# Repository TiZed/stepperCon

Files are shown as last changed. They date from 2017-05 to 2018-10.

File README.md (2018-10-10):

<b>stepperCon</b> is a PIC18F46K22 based stepper motor controller.

It was created as an exercise in controlling stepper motors for a CNC project. The board and firmware were designed to drive a L298P driver but can probably be adapted to other drivers.

'master' branch - Has hybrid PWM-analog current control. <br />
'a2d_pid' branch - Has the ADC PI current control, not stable yet.

Some of the feature of this project:
- Micro-stepping, selectable up to 16 micro-steps.
- Current limiting.
- I2C interface for configuration.
- Two indicator LEDs.

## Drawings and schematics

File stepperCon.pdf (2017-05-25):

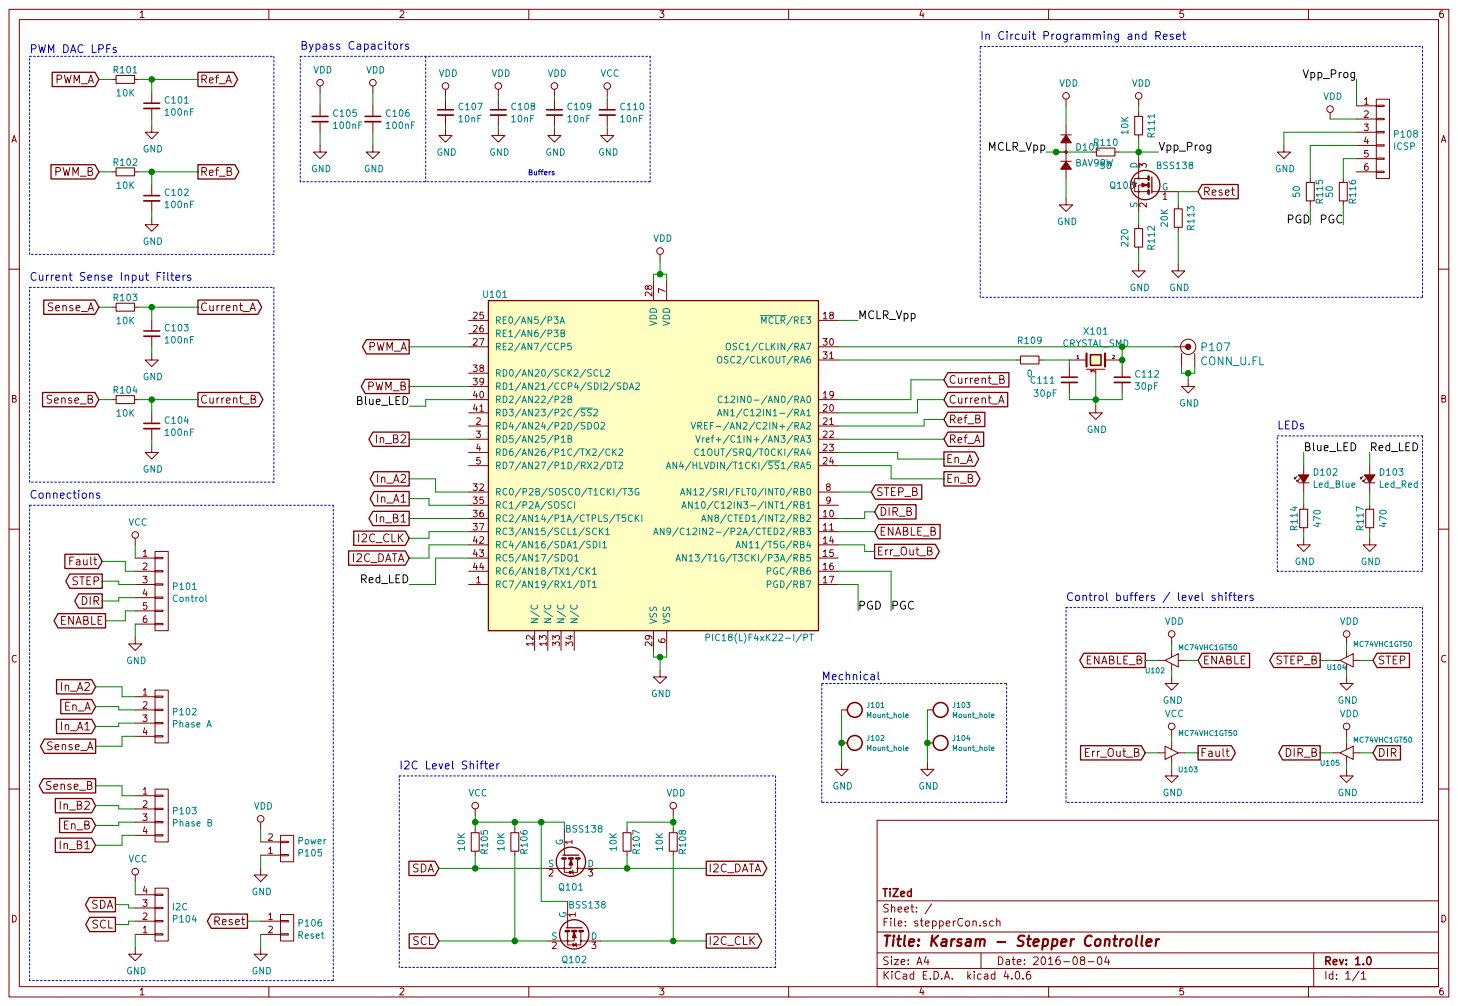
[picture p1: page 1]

In Circuit Programming and Reset

Current Sense Input Filters

7 AN12/SRI/FLT0/INT0/RB0 8 AN10/C12IN3-/INT1/RB1 9 AN8/CTED1/INT2/RB2 10 AN1/C12IN1-/RA1 20 OSC1/CLKIN/RA7 30 RD2/AN22/P2B 40 AN9/C12IN2-/P2A/CTED2/RB3 11 VREF-/AN2/C2IN+/RA2 21 OSC2/CLKOUT/RA6 31 RD3/AN23/P2C/SS2 41 N/C 12 Vref+/C1IN+/AN3/RA3 22 RC0/P2B/SOSCO/T1CKI/T3G 32 RC4/AN16/SDA1/SDI1 42 N/C 13 C1OUT/SRQ/T0CKI/RA4 23 N/C 33 RC5/AN17/SDO1 43 AN11/T5G/RB4 14 AN4/HLVDIN/T1CKI/SS1/RA5 24 N/C 34 RC6/AN18/TX1/CK1 44 AN13/T1G/T3CKI/P3A/RB5 15 RE0/AN5/P3A 25 RC1/P2A/SOSCI 35 PGC/RB6 16 RE1/AN6/P3B 26 RC2/AN14/P1A/CTPLS/T5CKI 36 PGD/RB7 17 RE2/AN7/CCP5 27 RC3/AN15/SCL1/SCK1 37 MCLR/RE3 18 VDD 28 RD0/AN20/SCK2/SCL2 38 C12IN0-/AN0/RA0 19 VSS 29 RD1/AN21/CCP4/SDI2/SDA2 39U101 PIC18(L)F4xK22-I/PT

Control buffers / level shifters

Id: 1/1 Title: Karsam - Stepper Controller

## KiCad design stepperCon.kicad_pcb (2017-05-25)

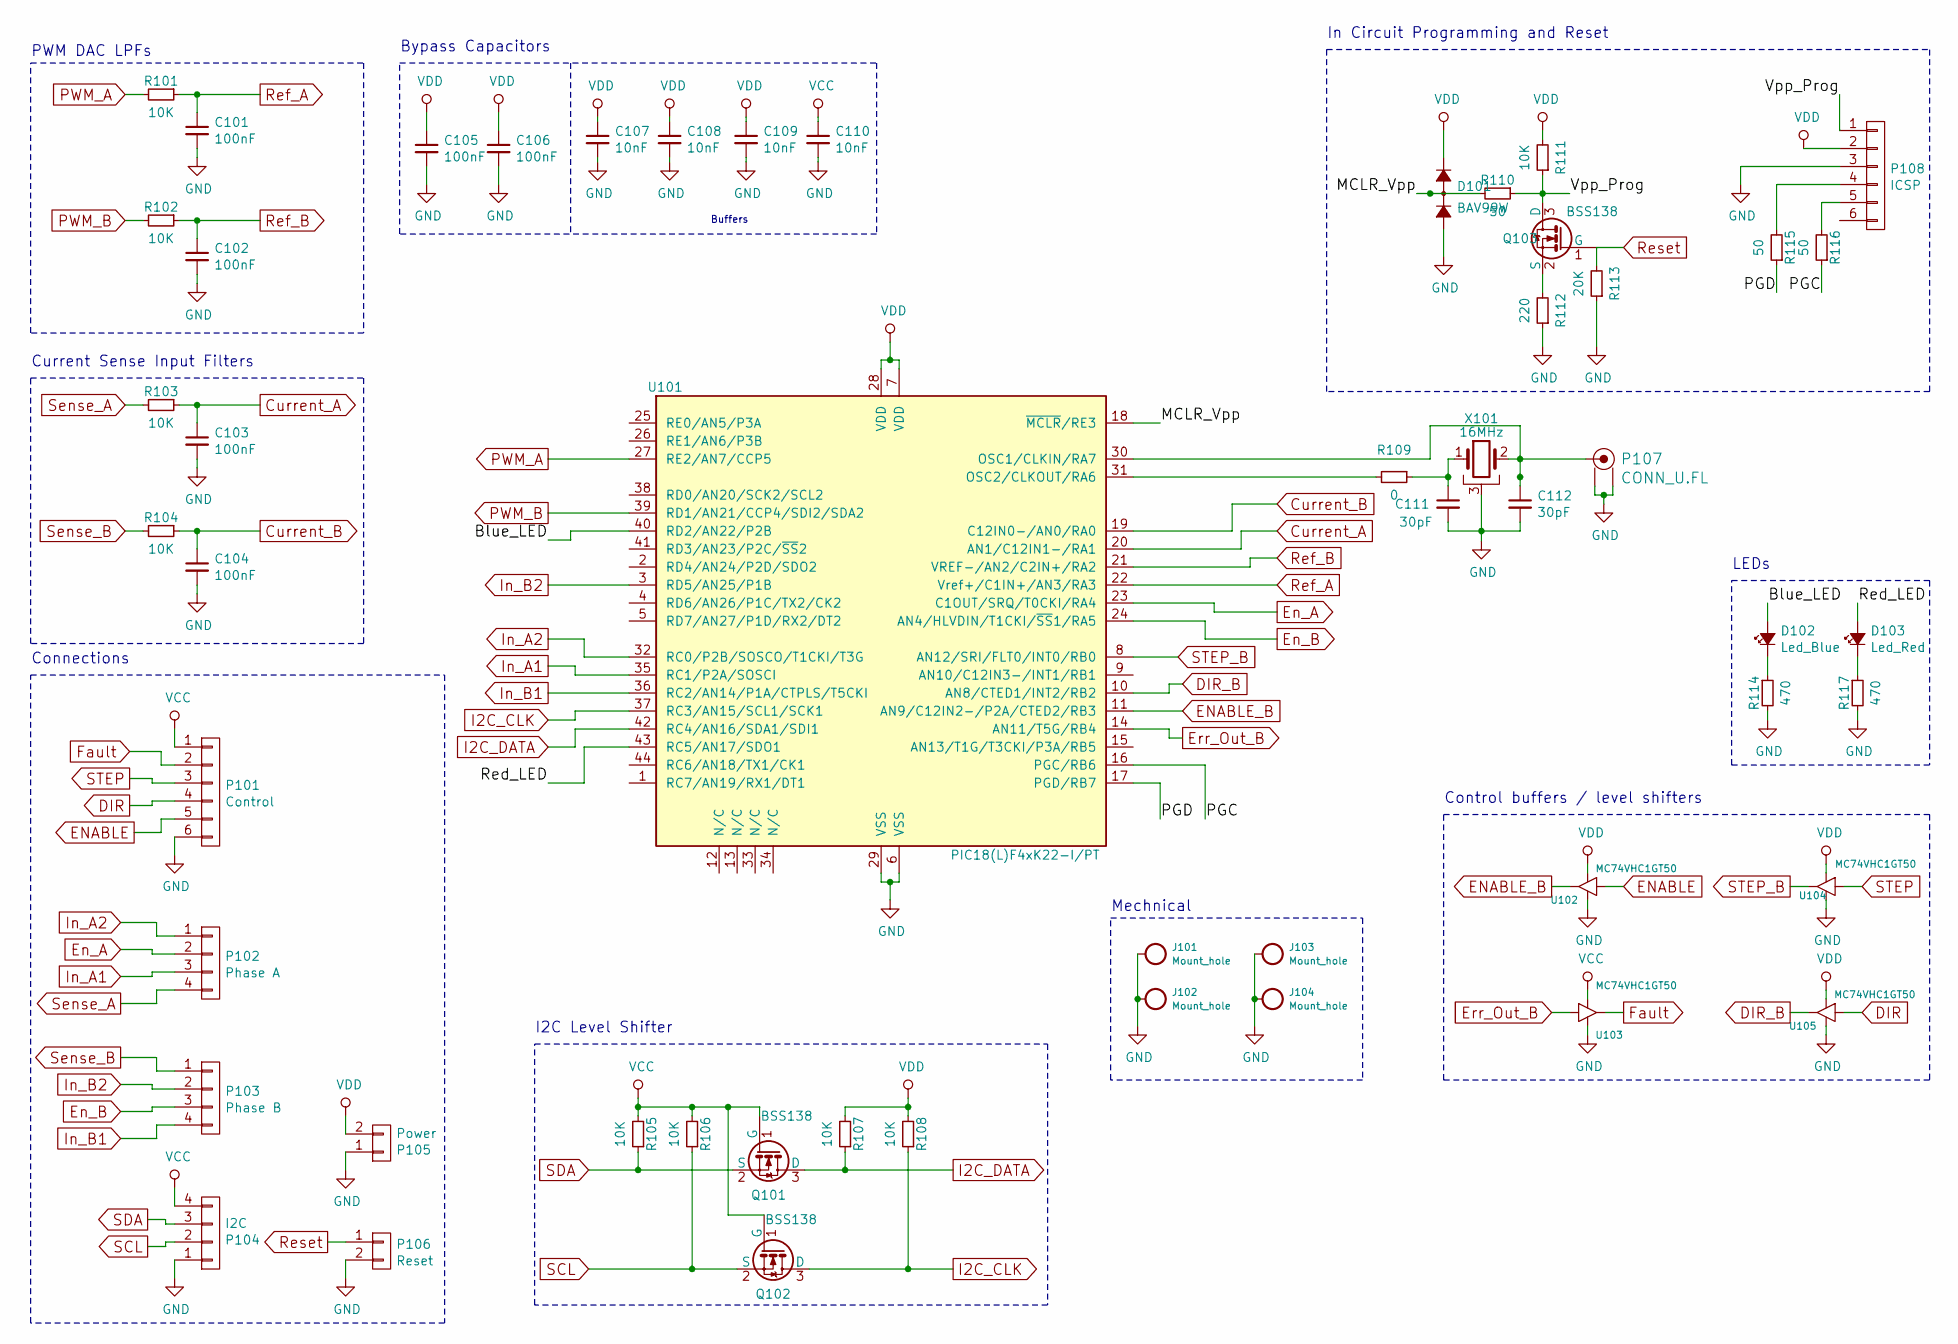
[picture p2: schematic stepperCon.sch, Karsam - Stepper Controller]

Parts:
C101, C102, C103, C104, C105, C106: 100nF; C_0603
C107, C108, C109, C110: 10nF; C_0603
C111, C112: 30pF; C_0603
D101: BAV99W; SOT-323
D102: Led_Blue; LED_0805
D103: Led_Red; LED_0805
J101, J102, J103, J104: Mount_hole; MountingHole_3.2mm_M3_Pad
P101: Control; Socket_Strip_Straight_1x06
P102: Phase A; Socket_Strip_Straight_1x04
P103: Phase B; Socket_Strip_Straight_1x04
P104: I2C; Socket_Strip_Straight_1x04
P105: Power; Socket_Strip_Straight_1x02
P106: Reset; Socket_Strip_Straight_1x02
P107: CONN_U.FL; UFL
P108: ICSP
Q101, Q102, Q103: BSS138; SOT-323
R101, R102, R103, R104, R105, R106, R107, R108, R111: 10K; R_0603
R109: 0; R_0603
R110, R115, R116: 50; R_0603
R112: 220; R_0603
R113: 20K; R_0603
R114, R117: 470; R_0603
U101: PIC18(L)F4xK22-I/PT; TQFP-44_10x10mm_Pitch0.8mm
U102, U103, U104, U105: MC74VHC1GT50; SOT-353
X101: 16MHz

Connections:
/Blue_LED: D102.2 (A), U101.40 (RD2/AN22/P2B)
/MCLR_Vpp: D101.3 (AK), R110.2, U101.18 (~MCLR~/RE3)
/PGC: R116.1, U101.16 (PGC/RB6)
/PGD: R115.1, U101.17 (PGD/RB7)
/Red_LED: D103.2 (A), U101.43 (RC5/AN17/SDO1)
/Vpp_Prog: P108.1, Q103.3 (D), R110.1, R111.1
Current_A: C103.1, R103.1, U101.20 (AN1/C12IN1-/RA1)
Current_B: C104.1, R104.1, U101.19 (C12IN0-/AN0/RA0)
DIR: P101.4, U105.2 (IN_A)
DIR_B: U101.10 (AN8/CTED1/INT2/RB2), U105.4 (OUT_Y)
ENABLE: P101.5, U102.2 (IN_A)
ENABLE_B: U101.11 (AN9/C12IN2-/P2A/CTED2/RB3), U102.4 (OUT_Y)
En_A: P102.2, U101.23 (C1OUT/SRQ/T0CKI/RA4)
En_B: P103.3, U101.24 (AN4/HLVDIN/T1CKI/~SS~1/RA5)
Err_Out_B: U101.14 (AN11/T5G/RB4), U103.2 (IN_A)
Fault: P101.2, U103.4 (OUT_Y)
GND: C101.2, C102.2, C103.2, C104.2, C105.2, C106.2, C107.2, C108.2, C109.2, C110.2, C111.2, C112.2, D101.1 (K), J101.1, J102.1, J103.1, J104.1, P101.6, P104.1, P105.1, P106.2, P107.2, P107.3, P108.3, R112.1, R113.1, R114.2, R117.2, U101.6 (VSS), U101.29 (VSS), U102.3 (GND), U103.3 (GND), U104.3 (GND), U105.3 (GND), X101.3
I2C_CLK: Q102.3 (D), R108.1, U101.37 (RC3/AN15/SCL1/SCK1)
I2C_DATA: Q101.3 (D), R107.1, U101.42 (RC4/AN16/SDA1/SDI1)
In_A1: P102.3, U101.35 (RC1/P2A/SOSCI)
In_A2: P102.1, U101.32 (RC0/P2B/SOSCO/T1CKI/T3G)
In_B1: P103.4, U101.36 (RC2/AN14/P1A/CTPLS/T5CKI)
In_B2: P103.2, U101.3 (RD5/AN25/P1B)
unnamed: C111.1, R109.1, X101.1
unnamed: C112.1, P107.1, U101.30 (OSC1/CLKIN/RA7), X101.2
unnamed: D102.1 (K), R114.1
unnamed: D103.1 (K), R117.1
unnamed: P108.4, R115.2
unnamed: P108.5, R116.2
unnamed: Q103.2 (S), R112.2
unnamed: R109.2, U101.31 (OSC2/CLKOUT/RA6)
PWM_A: R101.2, U101.27 (RE2/AN7/CCP5)
PWM_B: R102.2, U101.39 (RD1/AN21/CCP4/SDI2/SDA2)
Ref_A: C101.1, R101.1, U101.22 (Vref+/C1IN+/AN3/RA3)
Ref_B: C102.1, R102.1, U101.21 (VREF-/AN2/C2IN+/RA2)
Reset: P106.1, Q103.1 (G), R113.2
SCL: P104.2, Q102.2 (S), R106.1
SDA: P104.3, Q101.2 (S), R105.1
STEP: P101.3, U104.2 (IN_A)
STEP_B: U101.8 (AN12/SRI/FLT0/INT0/RB0), U104.4 (OUT_Y)
Sense_A: P102.4, R103.2
Sense_B: P103.1, R104.2
VCC: C110.1, P101.1, P104.4, Q101.1 (G), Q102.1 (G), R105.2, R106.2, U103.5 (VCC)
VDD: C105.1, C106.1, C107.1, C108.1, C109.1, D101.2 (A), P105.2, P108.2, R107.2, R108.2, R111.2, U101.7 (VDD), U101.28 (VDD), U102.5 (VCC), U104.5 (VCC), U105.5 (VCC)

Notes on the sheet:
I2C Level Shifter
PWM DAC LPFs
Current Sense Input Filters
Mechnical
Connections
Control buffers / level shifters
Bypass Capacitors
Buffers
LEDs
In Circuit Programming and Reset

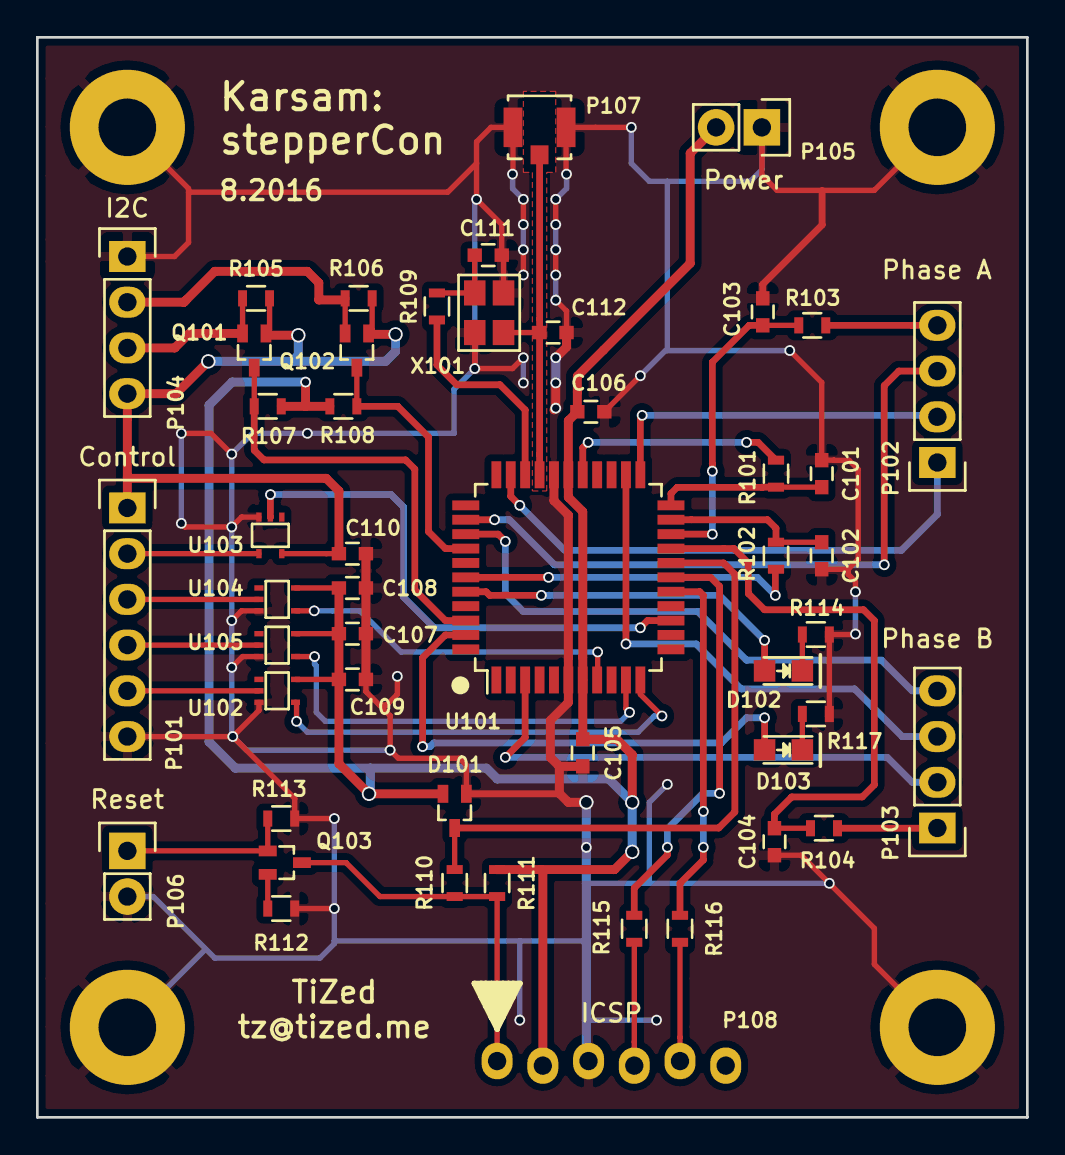
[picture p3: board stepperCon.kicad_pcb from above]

Board: 2 copper layers, 55.0 x 60.0 mm, 53 parts (0 on the bottom side), 44 nets.

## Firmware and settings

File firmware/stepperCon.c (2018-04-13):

/* 
 * File:   stepperCon.c
 * Author: TiZed
 *
 * Created on 12 August 2016
 * 
 *  Copyright (C) 2016 TiZed
 *
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
 * ----------------------------------------------------------------------------
 * 
 * 
 * * Phase A:
 * -------
 * RA1 - C12IN1- - Current sense in
 * RC1 - P2A - A1 Output
 * RC0 - P2B - A2 Output
 * RE2 - CCP5 - Analog out, connects to phase enable or AN3
 * RA3 - C1IN+ - Get reference voltage from PWM
 * RA4 - C1OUT - Phase enable signal from comparator
 * 
 * Phase B:
 * -------
 * RA0 - C12IN0- - Current sense in
 * RC2 - P1A - B1 Output
 * RD5 - P1B - B2 Output
 * RD1 - CCP4 - Analog out, connects to phase enable or AN3
 * RA2 - C2IN+ - Get reference voltage from PWM
 * RA5 - C2OUT - Phase enable signal from comparator
 * 
 * Controller I/F:
 * --------------
 * RB2 - INT2 - Direction Input
 * RB0 - INT0 - Step Input
 * RB3 - Enable Input
 * RB4 - Fault output
 * 
 * RC4 - SDA1 - I2C Data
 * RC3 - SCL1 - Clock
 * 
 * RD2 - Blue LED
 * RC5 - Red LED
 * 
 */

#include <pic18fregs.h>
#include <stdint.h>
#include <float.h>
#include <math.h>

#include "registers.h"

#pragma config  FOSC    = HSHP      // HS ocsillator, high power
#pragma config  PLLCFG  = ON        // x4 PLL on
#pragma config  WDTEN   = SWON      // WDT software controlled
#pragma config  XINST   = OFF       // For SDCC
#pragma config  CCP3MX  = PORTE0    // CCP3 on port E0   
#pragma config  P2BMX   = PORTC0    // P2B on port C0
#pragma config  MCLRE   = EXTMCLR   // Enable MCLR pin (E3 disabled)
// #pragma config  LVP     = ON        // Low voltage programming enabled

#define STEPS 16
#define FULL_CYCLE (4 * STEPS)
#define HALF_CYCLE (2 * STEPS)
#define THREE_QUARTERS (3 * STEPS)

// Some default values
#define CUR_GAIN 90         // Current sensor gain

#define I2C_ADDRESS 0x40    // X- 0x40, Y- 0x42, Z- 0x44 
#define I2C_REGISTERS 9


#define MAX_AMP 3704        // [mA] Maximum driver amperage
#define SET_AMP 1500        // [mA] Default driver limit
#define T_OFF   20          // [usec.] fixed phase time off
#define T_BLANK_HIGH 1      // [usec.] blank time for forward current
#define T_BLANK_LOW  10     // [usec.] blank time for revers current

// Stepping modes
#define STEP_16  1
#define STEP_8   2
#define STEP_4   4
#define STEP_2   8
#define STEP_1  16

// Decay modes
#define SLOW_DECAY 0
#define FAST_DECAY 1

// System states
#define IDLE      0
#define START     1
#define RUNNING   2
#define HALT      3
#define STEP      4
#define NEXT_STEP 6

// Phase states
#define PH_BLANK    0
#define PH_OFF      1
#define T_DRIVE     2

#define TMR_1MS   63536     // @1:8 Prescaller, Fosc/4
#define TMR_10MS  45536     // @1:8 Prescaller, Fosc/4
#define TMR_500NS 1         // @1:8 Prescaller, Fosc/4

#define PWM_MAX   1023

// Default EEPROM data
typedef unsigned char eeprom ;
__code eeprom __at 0xf00000 __EEPROM[] = { I2C_ADDRESS, STEP_8, SET_AMP, 
                                           SET_AMP >> 8, MAX_AMP, 
                                           MAX_AMP >> 8, T_OFF,
                                           T_BLANK_LOW, T_BLANK_HIGH};

// PWM micro-stepping base table
static const __data int16_t pwm_base[] = {  
        0,   50,  100,  149,  196,  241,  284,  325,    //  0-7 
      362,  396,  426,  452,  473,  490,  502,  510,    //  8-15
      512,  510,  502,  490,  473,  452,  426,  396,    // 16-23 
      362,  325,  284,  241,  196,  149,  100,   50,    // 24-31
        0,  -50, -100, -149, -196, -241, -284, -325,    // 32-39
     -362, -396, -426, -453, -473, -490, -502, -510,    // 40-47
     -512, -510, -502, -490, -473, -452, -426, -396,    // 48-55
     -362, -325, -284, -241, -196, -149, -100,  -50     // 56-63
} ;

uint8_t state ;             // Current state of operation state machine
uint8_t skip ;              // Reg 0x01 - Micro-stepping 

uint16_t set_amp ;          // Reg 0x02 (LSB) & 0x03 (MSB) 
uint16_t max_amp ;          // Reg 0x04 (LSB) & 0x05 (MSB)

uint8_t a_decay ;           // Phase A decay mode
uint8_t b_decay ;           // Phase B decay mode

uint8_t t_off ;             // Phase fixed off time, Reg 0x06
uint8_t t_blank_low ;       // Phase blanking in reverse current Reg 0x7
uint8_t t_blank_high ;      // Phase blanking in forward current Reg 0x8

int8_t step_a ;            // Current phase A step
int8_t step_b ;            // Current phase B step
uint8_t pol_a ;             // Phase A polarity
uint8_t pol_b ;             // Phase B polarity
int8_t  dir ;               // Direction

uint16_t pwm_lu[FULL_CYCLE] ;   // PWM lookup table
uint16_t zero_cross ;

uint8_t i2c_address ;       // Reg 0x00
uint8_t i2c_counter ;       // I2C bytes counter
uint8_t i2c_reg_addr ;      // Register address to read/write
uint8_t i2c_regs[I2C_REGISTERS] ;
uint8_t i2c_dirty ;         // I2C "dirty", does not match EEPROM

uint8_t a_state, b_state ;


extern void compsSetup(void) ;
extern void ioSetup(void) ;
extern void pwmSetup(void) ;
extern void intSetup(void) ;
extern void phTimersSetup(void) ;
extern void resetCheck(void) ;

// High priority interrupt
static void highInt(void) __interrupt(1) {
    // 'step' Interrupt
    if (INTCONbits.INT0IF) {
        state = STEP ;
        INTCONbits.INT0IF = 0 ;     // clear 'step' interrupt
    }
    
    // 'dir' Interrupts
    if (INTCON3bits.INT2IF) {
        
        if(PORTBbits.RB2) {
            // 'dir' is high trigger on falling edge next
            INTCON2bits.INTEDG2 = 0 ;   
            dir = 1 ;
        }
        else { 
            // 'dir' is low trigger on rising edge next
            INTCON2bits.INTEDG2 = 1 ;
            dir = -1 ;
        }

        state = NEXT_STEP ;         // Force recalculate of next step
        INTCON3bits.INT2IF = 0 ;    // clear 'dir' interrupt
    }
    
    // Phase-A off counter done
    if (PIR1bits.CCP1IF) {
        T1CONbits.TMR1ON = 0 ;  // Toff timer off
        TMR1L = 0 ;             // Clear off timer
        TMR1H = 0 ;
        
        if (a_state == PH_OFF) {
            if (a_decay == FAST_DECAY) {            
                if (pol_a) {                    // Forward current, Phase-A
                    LATCbits.LATC1 = 0 ;
                    LATCbits.LATC0 = 1 ;
                }
                else {                          // Reverse current, Phase-A
                    LATCbits.LATC0 = 0 ;
                    LATCbits.LATC1 = 1 ;
                }
            }     
            else LATAbits.LATA4 = 1 ;  // Toggle enable for slow decay
            
            CCPR1H = 0 ;
            
            if(pol_a) CCPR1L = t_blank_high ;
            else CCPR1L = t_blank_low ;
            
            a_state = PH_BLANK ;
            
            T1CONbits.TMR1ON = 1 ;
        }
        else if(a_state == PH_BLANK) {
            CCPR1H = 0 ;
            CCPR1L = t_off ;
            a_state = T_DRIVE ;
        }
        
        PIR1bits.CCP1IF = 0 ;
    }
    
    // Phase-B off counter done
    if (PIR2bits.CCP2IF) {
        T3CONbits.TMR3ON = 0 ;  // Toff timer off
        TMR3L = 0 ;             // Clear off timer 
        TMR3H = 0 ;
        
        if (b_state == PH_OFF) {
            // Reverse polarity for fast decay
            if (b_decay == FAST_DECAY) {
                if (pol_b) {                    // Forward current, Phase-B
                    LATCbits.LATC2 = 0 ;
                    LATDbits.LATD5 = 1 ;
                }
                else {                          // Reverse current, Phase-B
                    LATDbits.LATD5 = 0 ;
                    LATCbits.LATC2 = 1 ;
                }
            }
            else LATAbits.LATA5 = 1 ;  // Toggle enable for slow decay
            
            CCPR2H = 0 ;
            
            if(pol_b) CCPR2L = t_blank_high ;
            else CCPR2L = t_blank_low ;
            
            b_state = PH_BLANK ;
            
            T3CONbits.TMR3ON = 1 ;
        }
        else if(b_state == PH_BLANK) {
            CCPR2H = 0 ;
            CCPR2L = t_off ;
            b_state = T_DRIVE ;
        }
        
        PIR2bits.CCP2IF = 0 ;
    }
}

// Low priority interrupt
static void lowInt(void) __interrupt(2) {
    uint8_t i2c_buf = 0 ;
    
    // I2C Interrupt
    if (PIR1bits.SSP1IF) {
        if (SSP1STATbits.BF) i2c_buf = SSP1BUF ;    // Read data, clear BF
        
        // If address was received
        if (!SSP1STATbits.D) {
            i2c_counter = 0 ;                       // Reset counter
            if (SSP1STATbits.R) {                   // On read,
                SSP1BUF = i2c_regs[i2c_reg_addr++] ; // Send register value
            }
        }
        // If data received
        else {
            i2c_counter++ ;                         // Increment counter
            if (SSP1STATbits.R) {                   // On read,
                SSP1BUF = i2c_regs[i2c_reg_addr++] ; // Send register value
            }
            else {                                  // On write,
                if (i2c_counter == 1) {             // First byte is register
                    i2c_reg_addr = i2c_buf ;        // value
                }
                else {                              // Next bytes are data to 
                    i2c_regs[i2c_reg_addr++] = i2c_buf ; // write
                    i2c_dirty = 1 ;                 // set I2C dirty flag
                }
            }
        }
        
        i2c_reg_addr %= sizeof(i2c_regs) ;          // Prevent buffer overflow
        
        PIR1bits.SSP1IF = 0 ;       // Clear interrupt
        SSP1CON1bits.CKP = 1 ;      // Release clock
    }
    
    else if (PIR2bits.BCL1IF) {
        PIR2bits.BCL1IF = 0 ;       // Clear I2C collision interrupt
    } 
}

// Setup I2C I/F
void i2cSetup(void) {
    TRISCbits.TRISC3 = 1 ;      // Set I2C pins as input
    TRISCbits.TRISC4 = 1 ;
    
    SSP1CON1bits.SSPEN = 0 ;
    SSP1CON2bits.GCEN = 1 ;     // Enable general call on address 0x00
    SSP1CON2bits.SEN = 1 ;      // Enable clock stretching
    SSP1ADD = i2c_address ;     // Set device I2C address
    
    i2c_reg_addr = 0 ;
    
    SSP1CON1bits.SSPM = 0x6 ;   // I2C Slave mode, 7-bit address
}

// Prepare interrupts
void activeInts(void) {
    PIE1bits.SSP1IE = 0 ;       // Disable I2C interrupt
    SSP1CON1bits.SSPEN = 0 ;    // Disable I2C port
    PIE2bits.BCL1IE = 0 ;       // Disable I2C collision detection interrupt
    
    // 'dir' interrupt; falling edge if '1', rising edge '0' 
    if(PORTBbits.RB2) { 
        INTCON2bits.INTEDG2 = 0 ;
        dir = 1 ;
    }
    else { 
        INTCON2bits.INTEDG2 = 1 ;
        dir = -1 ;
    }
    
    INTCONbits.INT0IE = 1 ;     // Enable 'step' interrupt
    INTCON3bits.INT2IE = 1 ;    // Enable 'dir' interrupt
    
    PIE2bits.C1IE = 0 ;         // Disable Comparator C1 Interrupt
    PIE2bits.C2IE = 0 ;         // Disable Comparator C2 Interrupt
    
    PIE1bits.CCP1IE = 1 ;       // Enable CCP1 interrupt
    PIE2bits.CCP2IE = 1 ;       // Enable CCP2 interrupt
}

void idleInts(void) {
    INTCONbits.INT0IE = 0 ;     // Disable 'step' interrupt
    INTCON3bits.INT2IE = 0 ;    // Disable 'dir' interrupt
    
    PIE2bits.C1IE = 0 ;         // Disable Comparator C1 Interrupt
    PIE2bits.C2IE = 0 ;         // Disable Comparator C2 Interrupt
    
    PIE1bits.CCP1IE = 0 ;       // Disable CCP1 interrupt
    PIE2bits.CCP2IE = 0 ;       // Disable CCP2 interrupt
    
    PIE1bits.SSP1IE = 1 ;       // Enable I2C interrupt
    PIE2bits.BCL1IE = 1 ;       // Enable I2C collision detection interrupt
    
    SSP1CON1bits.SSPOV = 0 ;
    PIR1bits.SSP1IF = 0 ;
    SSP1CON1bits.CKP = 1 ;      // Release clock
    SSP1CON1bits.SSPEN = 1 ;    // Enable I2C port
}

// Calculate PWM lookup table
void prep_pwm_lu(void) {
    float ratio, set, bias ;
    uint8_t i ;
    
    ratio = (float)set_amp / (float)max_amp ;
    bias = (float)PWM_MAX / 2.0 ;
    
    zero_cross = __fs2uint(bias) ;
    
    for(i = 0 ; i < (sizeof(pwm_base) / sizeof(int16_t)) ; i++) {
        set = (float)pwm_base[i] * ratio + bias ;
        pwm_lu[i] = __fs2uint(set) ;
    }
}

// Get operation variables
void set_op_vars(void) {
    i2c_address = i2c_regs[0x00] ;
    skip        = i2c_regs[0x01] ;
    set_amp     = i2c_regs[0x02] ;
    set_amp    += i2c_regs[0x03] << 8 ;
    max_amp     = i2c_regs[0x04] ;
    max_amp    += i2c_regs[0x05] << 8 ;
    t_off       = i2c_regs[0x06] * 2 * TMR_500NS ;
    t_blank_low = i2c_regs[0x07] * 2 * TMR_500NS ;
    t_blank_high= i2c_regs[0x08] * 2 * TMR_500NS ;
}

// Basic msec. delay loop
void delay_ms(uint16_t time) {
    uint16_t i = time ;
    
    T0CON = 0x02 ;
    
    while(--i) {
        T0CONbits.TMR0ON = 0 ;
        INTCONbits.TMR0IF = 0 ;
        TMR0H = TMR_1MS >> 8 ;
        TMR0L = TMR_1MS ;
        T0CONbits.TMR0ON = 1 ;

        while(!INTCONbits.TMR0IF) ;
    }
    
    T0CONbits.TMR0ON = 0 ;
    INTCONbits.TMR0IF = 0 ;
}
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

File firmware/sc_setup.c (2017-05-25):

/* 
 * File:   sc_setup.c
 * Author: TiZed
 *
 * Created on 12 August 2016
 * 
 *  Copyright (C) 2016 TiZed
 *
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
 * ----------------------------------------------------------------------------
 * 
 */

#include <pic18fregs.h>
#include <stdint.h>

#define TMR_10MS  45535

void compsSetup(void) {
    ANSELAbits.ANSA0 = 1 ;      // Enable RA0 as analog input
    TRISAbits.TRISA0 = 1 ;
    
    ANSELAbits.ANSA1 = 1 ;      // Enable RA1 as analog input
    TRISAbits.TRISA1 = 1 ;
    
    ANSELAbits.ANSA2 = 1 ;      // Enable RA2 as analog input
    TRISAbits.TRISA2 = 1 ;
    
    ANSELAbits.ANSA3 = 1 ;      // Enable RA3 as analog input
    TRISAbits.TRISA3 = 1 ;
    
    CM1CON0 = 0x09 ;            // C12IN1- Goes to C1, Current of Phase-A
    CM2CON0 = 0x08 ;            // C12IN0- Goes to C2, Current of Phase-B
     
    CM2CON1bits.C1HYS = 0 ;     // Enable hysteresis for both comparators
    CM2CON1bits.C2HYS = 0 ;           
}

void ioSetup(void) {
    TRISBbits.RB4 = 0 ;     // Start with a cleared 'fault' signal
    PORTBbits.RB4 = 0 ;
    
    ANSELDbits.ANSD2 = 0 ;
    TRISDbits.RD2 = 0 ;     // Start with blue LED off
    PORTDbits.RD2 = 0 ;
    
    ANSELC = 0x00 ;         // Disable Port-C as analog input
   
    TRISCbits.RC5 = 0 ;     // Start with red LED off
    PORTCbits.RC5 = 0 ;
    
    TRISCbits.RC0 = 0 ;     // Phase-A outputs
    TRISCbits.RC1 = 0 ;
 //   ANSELAbits.ANSA4 = 0 ;
    TRISAbits.RA4 = 0 ;
    
    LATCbits.LATC0 = 0 ;
    LATCbits.LATC1 = 0 ;
    LATAbits.LATA4 = 0 ;
    
    TRISCbits.RC2 = 0 ;     // Phase-B outputs
    ANSELDbits.ANSD5 = 0 ;
    TRISDbits.RD5 = 0 ;
    ANSELAbits.ANSA5 = 0 ;
    TRISAbits.RA5 = 0 ;
    
    LATCbits.LATC2 = 0 ;
    LATDbits.LATD5 = 0 ; 
    LATAbits.LATA5 = 0 ;
    
    ANSELB = 0x00 ;         // Disable port B analog input
    
    TRISBbits.RB0 = 1 ;     // 'step', 'dir' and 'enable' as inputs
    TRISBbits.RB2 = 1 ;
    TRISBbits.RB3 = 1 ;
}

void pwmSetup(void) {
    ANSELEbits.ANSE2 = 0 ;
    TRISEbits.TRISE2 = 1 ;          // Disable driver for setup
    ANSELDbits.ANSD1 = 0 ;
    TRISDbits.TRISD1 = 1 ;
    
    CCPTMRS1 = 0x00 ;               // Use Timer2 for references
    PR2 = 0xff ;                    // Set timer for 62.5kHz @64MHz, 10-bit res
    T2CONbits.T2CKPS = 0x0 ;        // Set prescaler to 1:1
    T2CONbits.TMR2ON = 1 ;          // Turn timer on
    
    CCP5CONbits.CCP5M = 0x0c ;      // Enable Phase-A current reference
    CCP4CONbits.CCP4M = 0x0c ;      // Enable Phase-B current reference
    
    TRISEbits.TRISE2 = 0 ;          // Enable driver
    TRISDbits.TRISD1 = 0 ;
}

void intSetup(void) {
    INTCONbits.GIE_GIEH = 0 ;   // Disable interrupts
    INTCONbits.PEIE_GIEL = 0 ;
    
    RCONbits.IPEN = 1 ;         // Enable interrupts priority

    INTCON2bits.RBPU = 1 ;      // Disable Port B pull-ups
    INTCON2bits.INTEDG0 = 1 ;   // 'step' interrupt on rising edge
    
    INTCON3bits.INT2IP = 1 ;    // High priority to 'dir' interrupt
    
    IPR2bits.C1IP = 1 ;         // High priority to Phase-A comparator
    IPR2bits.C2IP = 1 ;         // High priority to Phase-B comparator
    
    IPR1bits.CCP1IP = 1 ;       // Hight priority to Phase-A compare timer
    IPR2bits.CCP2IP = 1 ;       // Hight priority to Phase-B compare timer
    
    IPR1bits.SSP1IP = 0 ;       // Low priority to I2C interrupt
    
    INTCONbits.GIE_GIEH = 1 ;   // Enable interrupts
    INTCONbits.PEIE_GIEL = 1 ;
}

void phTimersSetup(void) {
    // Prepare Timers 1 & 3 with 1:8 prescaler 
    // For Toff counters
    T1CONbits.TMR1CS = 0 ;
    T1CONbits.T1CKPS = 3 ;
    T1CONbits.TMR1ON = 0 ;
    TMR1L = 0 ;
    TMR1H = 0 ;
    
    T3CONbits.TMR3CS = 0 ;
    T3CONbits.T3CKPS = 3 ;
    T3CONbits.TMR3ON = 0 ;
    TMR3L = 0 ;
    TMR3H = 0 ;
    
    CCPTMRS0bits.C1TSEL = 0 ;   // Timer1 -> CCP1
    CCPTMRS0bits.C2TSEL = 1 ;   // Timer3 -> CCP2
    
    // CCP1 & 2 set to software interrupt mode
    CCP1CONbits.CCP1M = 0xa ;
    CCP2CONbits.CCP2M = 0xa ;
}

void resetCheck(void) {
    uint8_t i ;
    
    // On WDT timeout, Power down detect or brown-out
    if(!RCONbits.TO || !RCONbits.PD || !RCONbits.BOR) {
        // Reset RCON flags
        RCONbits.TO = 1 ;
        RCONbits.PD = 1 ;
        RCONbits.BOR = 0 ;
        RCONbits.POR = 0 ;

        PORTBbits.RB4 = 1 ;     // Rise 'fault' signal
        PORTCbits.RC5 = 1 ;     // Turn on red LED

        while(1) ; 
    }

    // On stack over/underflow
    if(STKPTRbits.STKFUL || STKPTRbits.STKUNF) {
        // Clear stack pointer flags
        STKPTRbits.STKFUL = 0 ;
        STKPTRbits.STKUNF = 0 ;

        PORTBbits.RB4 = 1 ;     // Rise 'fault' signal
        PORTCbits.RC5 = 1 ;     // Turn on red LED

        // Blink RED LED
        T1CONbits.TMR1CS = 0 ;      // Timer1 to Fosc/4
        i = 120 ;

        while(1) {
            T1CONbits.TMR1ON = 0 ;
            PIR1bits.TMR1IF = 0 ;
            T1CONbits.T1CKPS = 3 ;      // Timer1 1:8 prescale
            TMR1H = TMR_10MS >> 8 ;
            TMR1L = TMR_10MS ;
            T1CONbits.TMR1ON = 1 ;

            while(!PIR1bits.TMR1IF) ;

            if (--i == 0) {
                LATCbits.LATC5 = !LATCbits.LATC5 ;
                i = 120 ;
            }
        }
    }
}

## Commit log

2017-12-09 Selectable microstepping
    [Microstepping_calc.ods]
2018-02-09 Some comments to the code
    [stepperCon.sch]
2018-04-13 Adjusted current limit

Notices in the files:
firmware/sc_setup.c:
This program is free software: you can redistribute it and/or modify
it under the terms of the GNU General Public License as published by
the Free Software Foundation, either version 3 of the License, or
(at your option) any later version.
